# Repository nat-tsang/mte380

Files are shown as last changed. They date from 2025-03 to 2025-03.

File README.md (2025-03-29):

# Welcome to MTE380: PiDdy
We're a team of 5 students from the University of Waterloo tasked with creating a search and rescue robot to complete a course, via line following with computer vision, pick up a lego man and drop off the lego man in a safe zone. 

The course consists of a 6x6 grid of 30cm x 30cm squares, with a red tape path guiding the robot from the starting point to the target. A green tape box outlines two safe zones which the Lego man can be dropped off in. 

On game day, our robot was able to achieve times of 15 seconds on the first two runs, and 13 seconds in the third run. In total it weighed 131 g, mostly thanks to the mechanical and electrical design of the robot. The robot's software architecutre consisted of a Teensy MCU running the main control logic, and a Pixy camera module for the perception. 
# Software

This repo contains all of the software behind our robot, PiDdy. It specifically contains the PD controller for line following, the main state machine for feature arbitration between line following, picking up the lego man and dropping off the lego man.

## Code Standards

We are following OOP coding practices for clean, reusable code.

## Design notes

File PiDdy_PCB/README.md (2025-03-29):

Space for all things to do custom pcb (PiDdy's chassis)

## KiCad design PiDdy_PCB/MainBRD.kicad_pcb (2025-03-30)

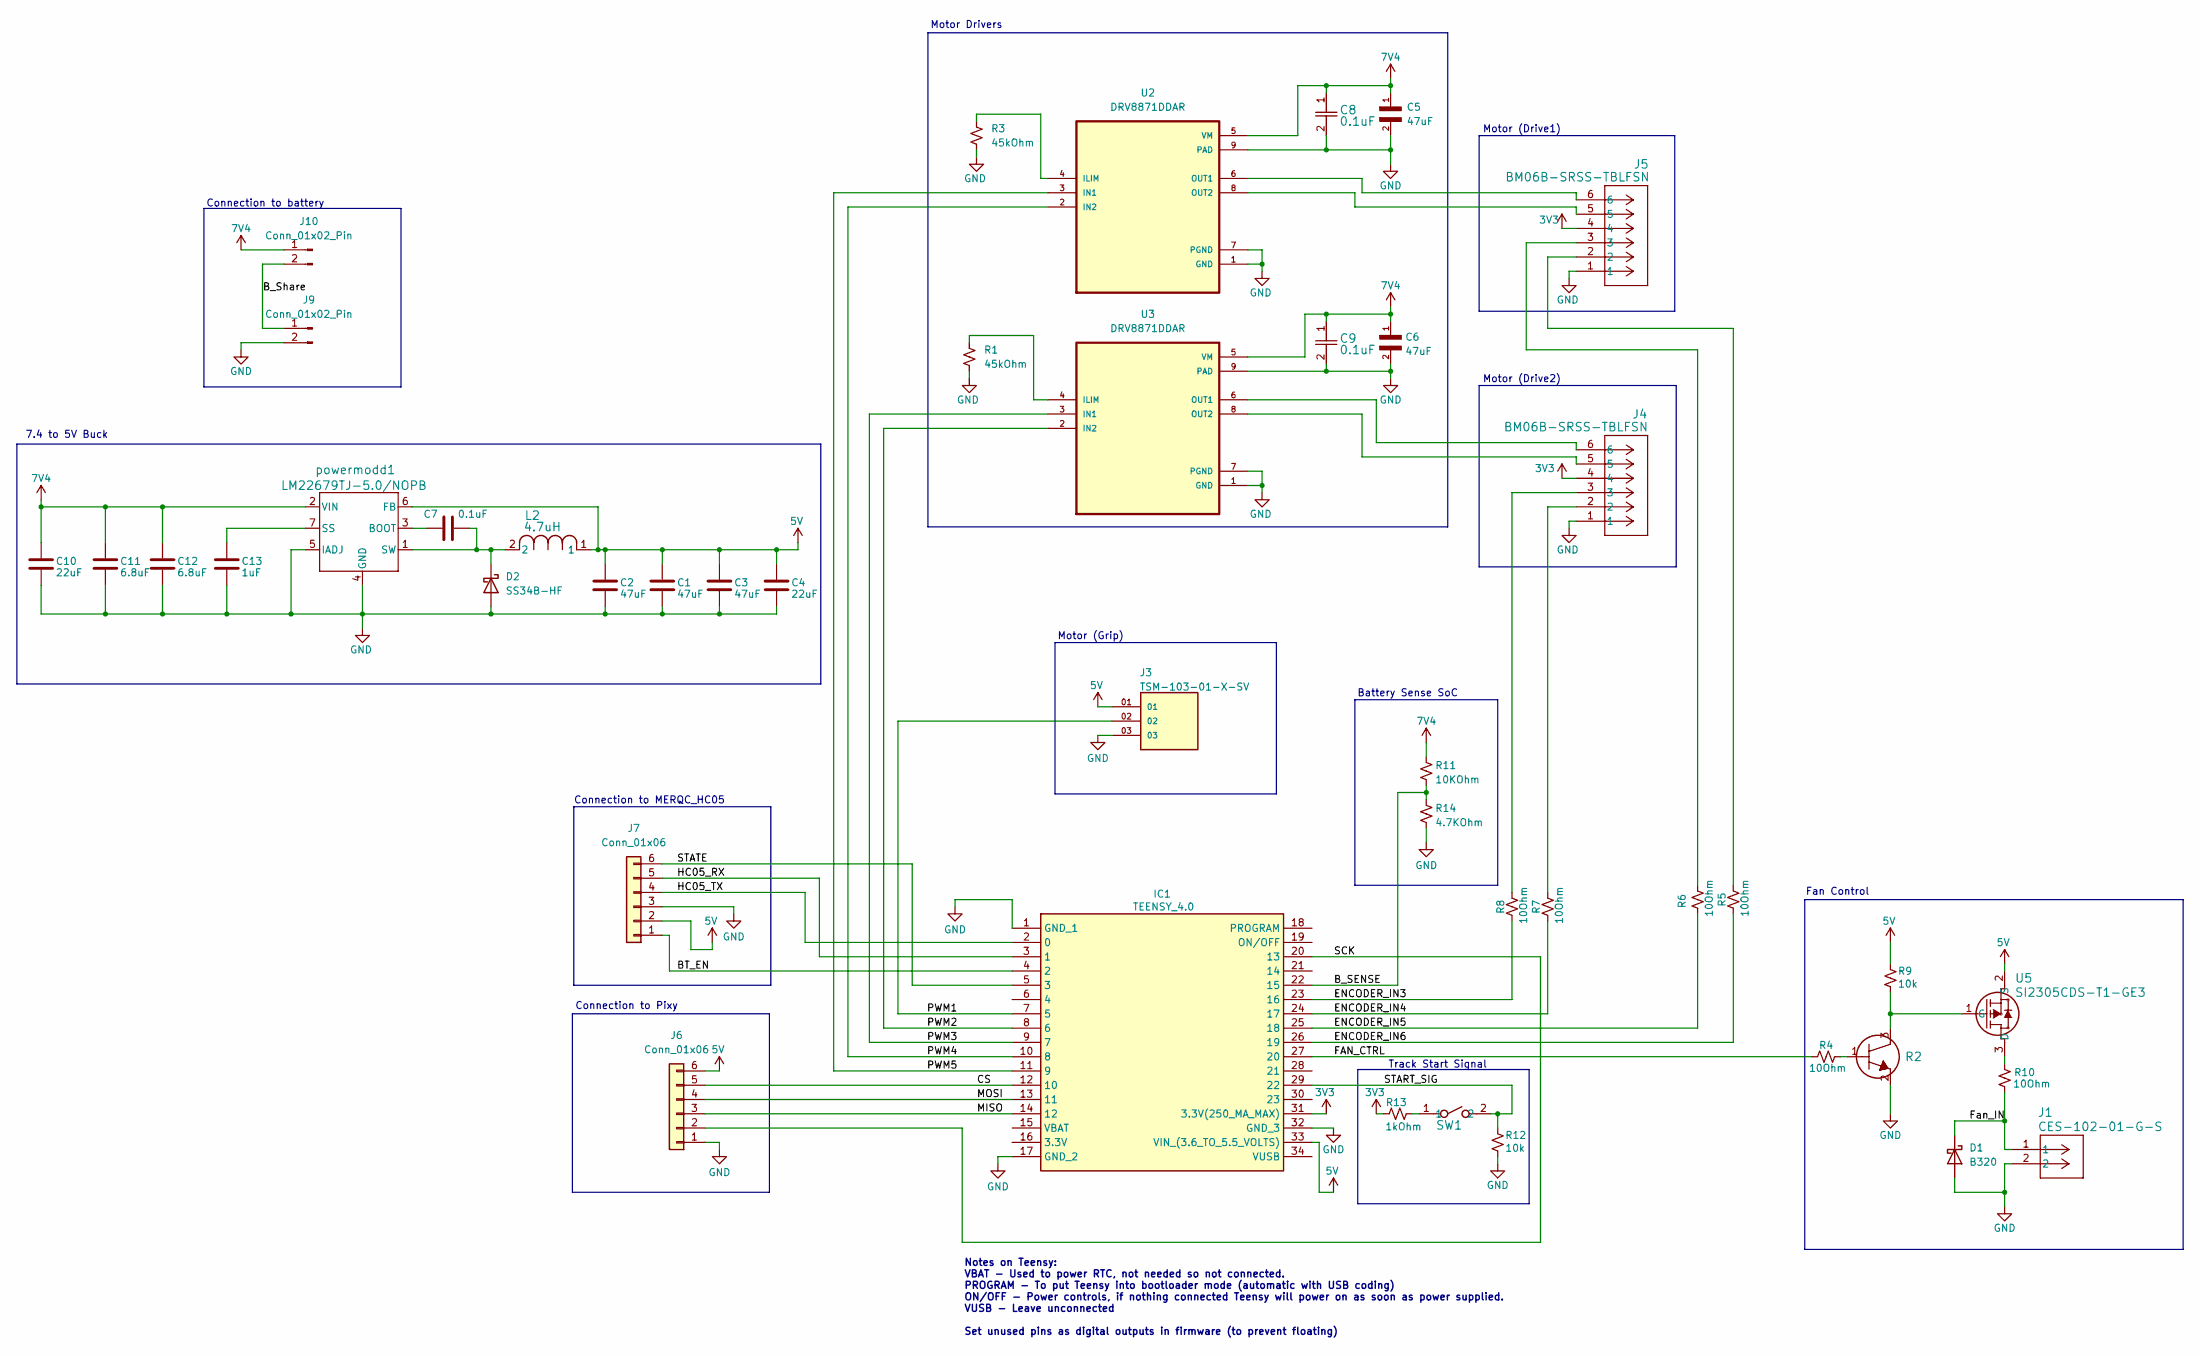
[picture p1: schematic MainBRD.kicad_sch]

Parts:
C1, C2, C3, C5, C6: 47uF; C_1210_3225Metric_Pad1.33x2.70mm_HandSolder
C4, C10: 22uF; C_1206_3216Metric_Pad1.33x1.80mm_HandSolder
C7: 0.1uF; C_0402_1005Metric_Pad0.74x0.62mm_HandSolder
C8, C9: 0.1uF; C_0402_1005Metric
C11: 6.8uF; LED_0805_2012Metric_Pad1.15x1.40mm_HandSolder
C12: 6.8uF; C_0805_2012Metric_Pad1.18x1.45mm_HandSolder
C13: 1uF; C_0402_1005Metric_Pad0.74x0.62mm_HandSolder
D1: B320; D_SMC
D2: SS34B-HF; SS34B
IC1: TEENSY_4.0; TEENSY40; Manufacturer_Part_Number TEENSY 4.0
J1: CES-102-01-G-S; CON2_1X2_TU_SLW_SAI
J3: TSM-103-01-X-SV; SAMTEC_TSM-103-01-X-SV; PARTREV D
J4, J5: BM06B-SRSS-TBLFSN; CONN_BM06B-SRSS-TB_JST
J6, J7: Conn_01x06; PinHeader_1x06_P2.54mm_Vertical
J9, J10: Conn_01x02_Pin; PinHeader_1x02_P2.54mm_Vertical
L2: 4.7uH; IND_VLS5045EX-4R7M
R1, R3: 45kOhm; RES_ERJ3EKF4532V
R2: 2SC5663T2L; TRANS_2SC5658T2_ROM
R4, R5, R6, R7, R8, R10: 10Ohm; ERJ_2RKF10R0X
R9, R12: 10k; RES_ERJ2RKF4702X
R11: 10KOhm; R_1206_3216Metric
R13: 1kOhm; ERJ_2RKF10R0X
R14: 4.7KOhm; R_1206_3216Metric
SW1: PTS636 SM50J SMTR LFS; SW_PTS636_CNK
U2, U3: DRV8871DDAR; lili_foot
U5: SI2305CDS-T1-GE3; TO-236_VIS
powermodd1: LM22679TJ-5.0/NOPB; LM22679TJ

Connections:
3V3: IC1.31 (3.3V(250_MA_MAX)), J4.4, J5.4, R13.2
5V: C1.1, C2.1, C3.1, C4.1, IC1.33 (VIN_(3.6_TO_5.5_VOLTS)), J3.01, J6.6, J7.2, L2.1, R9.1, U5.2 (S), powermodd1.6 (FB)
7V4: C5.1, C6.1, C8.1, C9.1, C10.1, C11.1, C12.1, J10.1, R11.1, U2.5 (VM), U3.5 (VM), powermodd1.2 (VIN)
/BT_EN: IC1.4 (2), J7.1
/B_SENSE: IC1.22 (15), R11.2, R14.1
/B_Share: J9.1, J10.2
/CS: IC1.12 (10), J6.5
/ENCODER_IN3: IC1.23 (16), R8.2
/ENCODER_IN4: IC1.24 (17), R7.2
/ENCODER_IN5: IC1.25 (18), R6.2
/ENCODER_IN6: IC1.26 (19), R5.2
/FAN_CTRL: IC1.27 (20), R4.2
/Fan_IN: D1.1 (K), J1.1, R10.2
/HC05_RX: IC1.3 (1), J7.5
/HC05_TX: IC1.2 (0), J7.4
/MISO: IC1.14 (12), J6.3
/MOSI: IC1.13 (11), J6.4
/PWM1: IC1.7 (5), J3.02
/PWM2: IC1.8 (6), U3.2 (IN2)
/PWM3: IC1.9 (7), U3.3 (IN1)
/PWM4: IC1.10 (8), U2.2 (IN2)
/PWM5: IC1.11 (9), U2.3 (IN1)
/SCK: IC1.20 (13), J6.2
/START_SIG: IC1.29 (22), R12.1, SW1.2
/STATE: IC1.5 (3), J7.6
GND: C1.2, C2.2, C3.2, C4.2, C5.2, C6.2, C8.2, C9.2, C10.2, C11.2, C12.2, C13.2, D1.2 (A), D2.2 (A), IC1.1 (GND_1), IC1.17 (GND_2), IC1.32 (GND_3), J1.2, J3.03, J4.1, J5.1, J6.1, J7.3, J9.2, R1.1, R2.2 (EMITTER), R3.1, R12.2, R14.2, U2.1 (GND), U2.7 (PGND), U2.9 (PAD), U3.1 (GND), U3.7 (PGND), U3.9 (PAD), powermodd1.4 (GND), powermodd1.5 (IADJ)
unnamed: C7.2, D2.1 (K), L2.2, powermodd1.1 (SW)
unnamed: J4.2, R7.1
unnamed: J4.3, R8.1
unnamed: J5.2, R5.1
unnamed: J5.3, R6.1
unnamed: R2.1 (Base), R4.1
unnamed: R2.3 (Collector), R9.2, U5.1 (G)
unnamed: R13.1, SW1.1
unnamed: R3.2, U2.4 (ILIM)
unnamed: J5.6, U2.6 (OUT1)
unnamed: J5.5, U2.8 (OUT2)
unnamed: R1.2, U3.4 (ILIM)
unnamed: J4.6, U3.6 (OUT1)
unnamed: J4.5, U3.8 (OUT2)
unnamed: R10.1, U5.3 (D)
unnamed: C7.1, powermodd1.3 (BOOT)
unnamed: C13.1, powermodd1.7 (SS)

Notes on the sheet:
Motor (Grip)
Motor (Drive1)
Connection to Pixy
Motor (Drive2)
Track Start Signal
Motor Drivers
Connection to battery
Notes on Teensy: VBAT - Used to power RTC, not needed so not connected. PROGRAM - To put Teensy into bootloader mode (automatic with USB coding) ON/OFF - Power controls, if nothing connected Teensy will power on as soon as power supplied. VUSB - Leave unconnected Set unused pins as digital outputs 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
Battery Sense SoC
Connection to MERQC_HC05
Fan Control
7.4 to 5V Buck

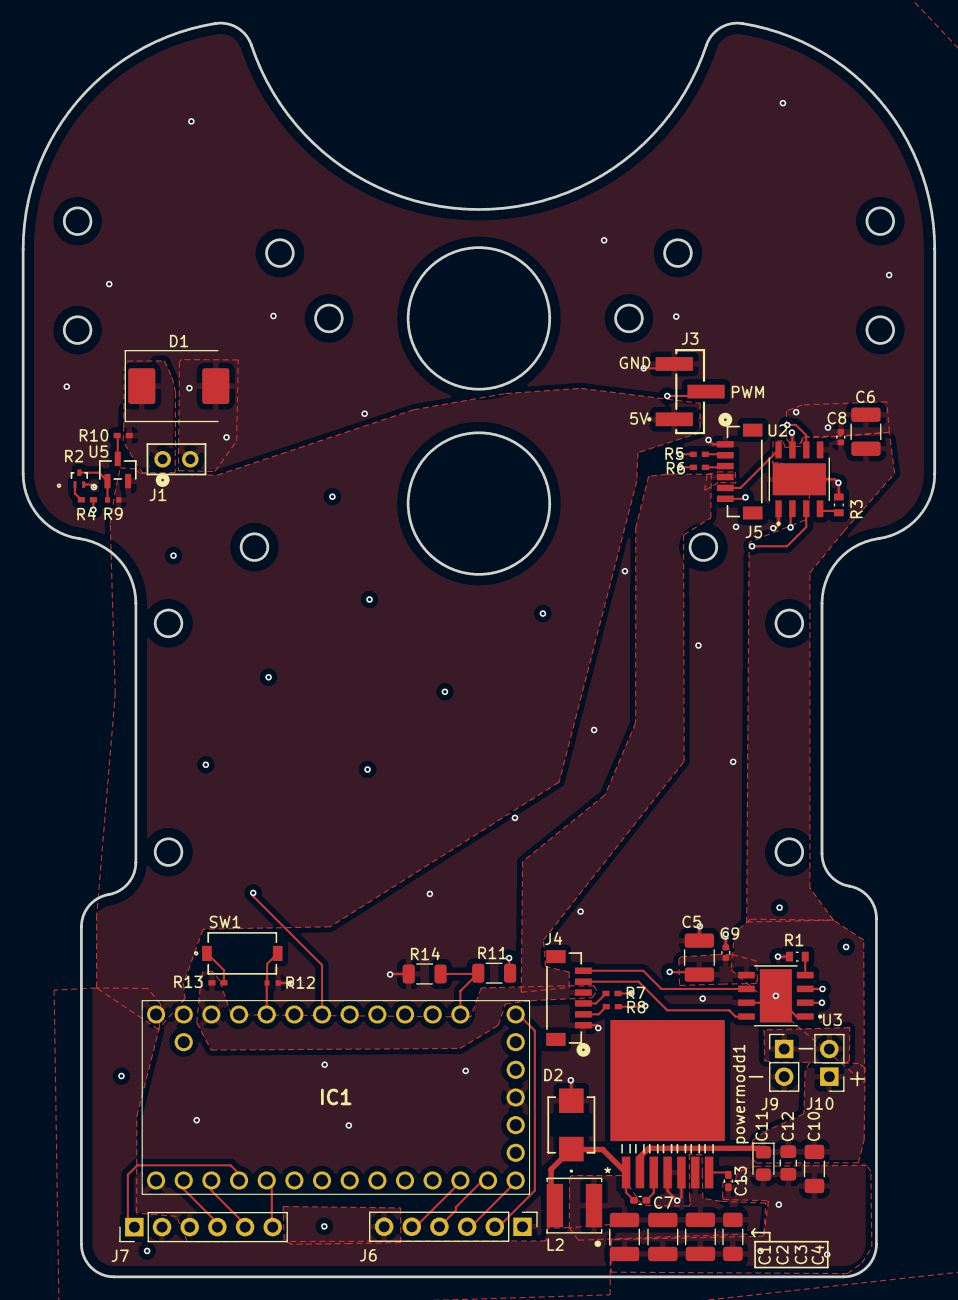
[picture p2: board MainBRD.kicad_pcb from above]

Board: 4 copper layers, 83.7 x 115.1 mm, 44 parts (0 on the bottom side), 43 nets.

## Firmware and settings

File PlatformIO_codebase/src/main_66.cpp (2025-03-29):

/**
 * @brief This main loop runs the main state diagram for Piddy with steering detection
 * THIS IS SWITCH CASE VERSION 
*/

#include <Arduino.h>
#include <Config.h>
#include <Motor.h>
#include <Fan.h>
#include <ServoGripper.h>
#include <PixyLineTracker.h>
#include <PIDController.h>
#include <Helpers.h>
#include <Filter.h>
#include <TurnController.h>
#include <EncoderReader.h>
// #define BTSerial Serial1

EncoderReader rightEncoder(ENCODER_IN6, ENCODER_IN5);
EncoderReader leftEncoder(ENCODER_IN3, ENCODER_IN4);

Motor rightMotor(u2_IN1, u2_IN2, true);
Motor leftMotor(u3_IN1, u3_IN2, false);

Fan fan(FAN);
ServoGripper gripper(SERVO, minPulse, maxPulse);

// Instantiate PID with gains from Config
PIDController linePID(LINE_KP, LINE_KI, LINE_KD);

PixyLineTracker lineTracker; // Pixy object for line, bullseye and legoman detection
Pixy2 pixy;

Filter<float, 3> pixyErrorFilter;    // For Pixy X-position (float)

bool hasTurned = false;

TurnController turnController(leftMotor, rightMotor, leftEncoder, rightEncoder, WHEEL_BASE, WHEEL_DIAMETER);

enum PiddyState {
  LINE_FOLLOW_PICKUP,
  LINE_FOLLOW_DROPOFF,
  BULLSEYE_DETECT,
  LEGOMAN_ALIGN,
  PICKUP_LEGOMAN,
  UNLOAD_SHAYLA,
  GO_HOME,
  IDLE
};

PiddyState currentState = IDLE;

// === Function Prototype ===
void printVoltageLevel(int analogPin);
void debugPrint(String msg);
bool legoManAlign(int thresholdX, int thresholdY, const Block* block, int numBlock);
float checkBatteries(int pin);
void flashPixyLight(int times);


void setup() {
  Serial.begin(115200);
  BTSerial.begin(9600);

  gripper.attach(); // Attach servo at startup
  gripper.close();

  initButton(START_SIG);  // Initialize button pin
  linePID.reset();
  //fan.turnOn(); // Turn fan on at startup

  lineTracker.begin();  // Initialize Pixy
  lineTracker.setLampOFF();

  pinMode(BATTERY_LEVEL_PIN, INPUT); // Battery level

  debugPrint("Code uploaded. STARTING ROUTINE");
  checkBatteries(BATTERY_LEVEL_PIN);  // Check battery voltage
  delay(1000);
}


void loop() {
  if (SYSTEM_SHUTDOWN) return;  // Halt program here if shutdown triggered
  // === Read battery voltage ===
  checkBatteries(BATTERY_LEVEL_PIN);  // Check battery voltage
  
  static bool lastRobotRunning = false;
  // === Check button state ===
  checkButton(leftMotor, rightMotor);  // Check button state and toggle robotRunning state

  // === State toggle logic ===
  if (robotRunning != lastRobotRunning) { // If button state changes
    if (robotRunning) {
      debugPrint("Switching to LINE_FOLLOWING");
      gripper.open();  // Optional: ready for pickup
      lineTracker.setBullseye(false);
      currentState = LINE_FOLLOW_PICKUP;
      //currentState = LINE_FOLLOW_DROPOFF;   // FOR TESTING ONLY
    } else {
      debugPrint("Switching to IDLE");
      hasTurned = false;
      leftbasePWM = 95;
      rightbasePWM = 95;
      currentState = IDLE;
    }
  }
  lastRobotRunning = robotRunning;

  pixy.ccc.getBlocks();
  const auto* blocks = pixy.ccc.blocks;
  int numBlocks = pixy.ccc.numBlocks;

  switch (currentState) {
    case IDLE:
      leftMotor.stop();
      rightMotor.stop();
      break; 

    case LINE_FOLLOW_PICKUP: {
      float pixyError = lineTracker.readLinePosition(blocks, numBlocks);  // +157.5 (far left drift) to -157.5 (far right drift)

      // TODO: Check in Pixy if the following parameters are correct
      lineTracker.findBullseye(100, 5, 30, 20, blocks, numBlocks, leftMotor, rightMotor); // currently on nightime, 175, 50, 30, 20 (daytime) 175, 50, 50, 20 (more forgiving x)
      if (lineTracker.getBullseye()) {
        leftMotor.stop();
        rightMotor.stop();
        leftMotor.setSpeed(-70); // Reverse robot
        rightMotor.setSpeed(-70);
        delay(100);
        leftMotor.stop();
        rightMotor.stop();
        flashPixyLight(1);
        leftbasePWM = 66;
        rightbasePWM = 66;
        currentState = LEGOMAN_ALIGN;
        break;
      }
      if (!lineTracker.getLineDetected()) {
        debugPrint("No line seen in LINE_FOLLOW_PICKUP");
        leftMotor.stop();
        rightMotor.stop();
        linePID.reset();
        break; 
      }

      if (abs(pixyError) < 10.0) {
        pixyError = 0;
      }
      double steeringCorrection = linePID.compute(pixyError);  // Output is differential m/s, -ve means turn left, +ve means turn right
      int leftPWM = constrain(leftbasePWM + steeringCorrection, 0, 150);
      int rightPWM = constrain(rightbasePWM - steeringCorrection, 0, 150);
      // === Apply Motor Commands ===
      leftMotor.setSpeed(leftPWM);
      rightMotor.setSpeed(rightPWM);  
      break;
    }

    case LEGOMAN_ALIGN: {
      if (legoManAlign(20, 150, blocks, numBlocks)) {
        debugPrint("Legoman centered. Switching to PICKUP_LEGOMAN");
        currentState = PICKUP_LEGOMAN;
      }
      break;
    }

    case PICKUP_LEGOMAN: {
      delay(150);
      gripper.close();
      debugPrint("Turning 180 with legoman. ");
      delay(300); // debouncing, allows gripper to fully close 
      if (!hasTurned) {
        turnController.turnDegrees(-150, 70); // 70 from testing in driveAndTurn.cpp
        hasTurned = true;
        delay(250); // Allow robot to stop and not drit past red line?
      }
      lineTracker.readLinePosition(blocks, numBlocks);
      debugPrint(lineTracker.getLineDetected());
      delay(200);
      if (lineTracker.getLineDetected()){
        lineTracker.setBullseye(false);
        linePID.reset();
        debugPrint("Switching to LINE_FOLLOW_DROPOFF");
        currentState = LINE_FOLLOW_DROPOFF;
      } else {
        turnController.turnDegrees(-30, 70);
      }
      break;
    }

    case LINE_FOLLOW_DROPOFF: {
      float pixyError = lineTracker.readLinePosition(blocks, numBlocks);  // +157.5 (far left drift) to -157.5 (far right drift)
      lineTracker.findGreenBox(0, 0, 0, 0, blocks, numBlocks); // passing in zeros because they are unused
      
      if (lineTracker.getGreenBox()) {    // TODO: Write function for turning and open servo and reverse and follow line home
        leftMotor.stop();
        rightMotor.stop();
        debugPrint("Green box found in stopping range. Setting to UNLOAD_SHAYLA");
        delay(400);
        currentState = UNLOAD_SHAYLA;

        break;
      }
      
      if (!lineTracker.getLineDetected()) {
        debugPrint("No line seen in LINE_FOLLOW_DROPOFF");
        leftMotor.stop();
        rightMotor.stop();
        linePID.reset();
        break; 
      }
      
      if (abs(pixyError) < 10.0) {
        pixyError = 0;
      }

      double steeringCorrection = linePID.compute(pixyError);  // Output is differential m/s, -ve means turn left, +ve means turn right
      int leftPWM = constrain(leftbasePWM + steeringCorrection, 0, 150);
      int rightPWM = constrain(rightbasePWM - steeringCorrection, 0, 150);
      // === Apply Motor Commands ===
      leftMotor.setSpeed(leftPWM);
      rightMotor.setSpeed(rightPWM);  
      break;
    }

    case UNLOAD_SHAYLA: {
      debugPrint("Dropping off Shayla in green box");
      turnController.turnDegrees(60, 70); // Turn to face green box
      delay(100); // Wait for turn to complete
      leftMotor.setSpeed(70); // Move robot forward
      rightMotor.setSpeed(70);
      delay(300); // Wait for robot to move forward
      leftMotor.stop();
      rightMotor.stop();
      delay(200); // Wait for robot to stop
      gripper.open();
      delay(200); // Wait for gripper to open
      leftMotor.setSpeed(-65); // Reverse robot
      rightMotor.setSpeed(-65);
      delay(500); // Wait for robot to reverse
      leftMotor.stop();
      rightMotor.stop();
      turnController.turnDegrees(65, -70); // Turn back to face line
      lineTracker.setGreenBox(false);
      debugPrint("Setting to GO_HOME");
      currentState = GO_HOME;
      break;
    }

    case GO_HOME: {
      float pixyError = lineTracker.readLinePosition(blocks, numBlocks);  // +157.5 (far left drift) to -157.5 (far right drift)

      if (!lineTracker.getLineDetected()) {
        debugPrint("No line seen in GO_HOME. Stopping");
        leftMotor.stop();
        rightMotor.stop();
        linePID.reset();
        break; 
      }

      if (abs(pixyError) < 10.0) {
        pixyError = 0;
      }

      double steeringCorrection = linePID.compute(pixyError);  // Output is differential m/s, -ve means turn left, +ve means turn right
      int leftPWM = constrain(leftbasePWM + steeringCorrection, 0, 150);
      int rightPWM = constrain(rightbasePWM - steeringCorrection, 0, 150);
      // === Apply Motor Commands ===
      leftMotor.setSpeed(leftPWM);
      rightMotor.setSpeed(rightPWM);  
      break;
    }

    default:
      // safety catch 
      leftMotor.stop();
      rightMotor.stop();
      currentState = IDLE;
      break;
  } 
}


// === Reads actual voltage using analog pin and divider ===
float checkBatteries(int pin) {
  static unsigned long lastPrintTime = 0;
  unsigned long currentTime = millis();

  float batteryVoltage = ((analogRead(pin)/ANALOG_RESOLUTION) * 3.3)/0.3197;

  // Only print every 5000 ms (5 seconds)
  if (currentTime - lastPrintTime >= 5000) {
    debugPrint("Battery Voltage: " + String(batteryVoltage));
    lastPrintTime = currentTime;
  }

  if (batteryVoltage < BATTERY_VOLTAGE_THRESHOLD) {
    debugPrint("Battery low. SYSTEM SHUTDOWN");
    SYSTEM_SHUTDOWN = true;
    currentState = IDLE;
    leftMotor.stop();
    rightMotor.stop();
    fan.turnOff();
    flashPixyLight(5);
  }
  return batteryVoltage;
}

// === Flashes Pixy cam lamp ===
void flashPixyLight(int times) {
  for (int i = 0; i < times; i++) {
    pixy.setLamp(1, 1); // LEDs ON
    delay(100);
    pixy.setLamp(0, 0); // LEDs OFF
    delay(100);
  }
}

bool legoManAlign(int thresholdX, int thresholdY, const Block* block, int numBlock) {     // TODO: Do we need to call get blocks again?
  auto [x, y] = lineTracker.getPixyCoord(6, block, numBlock); // orange shayla is 6,  TODO: Put in config
  debugPrint("Shayla x: " + String(x) + "   |   y: " + String(y));

  if (x >= 0 && y >= 0) {
    int x_error = (X_CENTER + 4) - x; // positive if legoman is to the left, negative if legoman is to the right
    debugPrint("Shayla x_error: " + String(x_error));

    if (abs(x_error) < thresholdX && y > thresholdY) { 
      debugPrint("Shayla is centered, stopping");
      leftMotor.stop();
      rightMotor.stop();
      return true;
    } 
    else {
      if (abs(x_error) < thresholdX) { 
        debugPrint("Shayla is centered");
        // drive forward only once Shayla is centered
        if (y < thresholdY) { // Legoman is too far, drive forward slowly
          debugPrint("Legoman is too far");
          leftMotor.setSpeed(75);
          rightMotor.setSpeed(75);
          debugPrint("Left PWM: " + String(leftMotor.getSpeed()) + "  |   Right PWM: " + String(rightMotor.getSpeed()));
          delay(100);
          leftMotor.setSpeed(0);
          rightMotor.setSpeed(0);
          delay(75);
        }
      }
      else if (abs(x_error) > thresholdX) {    // Turn robot on it's center axis
        debugPrint("Shayla is not centered");
        //int turnSpeed = abs(x_error * LEGO_KPx);    // Positive means turn right, negative means turn left
        if (x_error > 0) {   // Positive means turns left  
          leftMotor.setSpeed(0);
          rightMotor.setSpeed(75);
          delay(100);
          debugPrint("Left PWM: " + String(leftMotor.getSpeed()) + "  |   Right PWM: " + String(rightMotor.getSpeed()));
          leftMotor.setSpeed(0);
          rightMotor.setSpeed(0);
          delay(75); 
        }
        else if (x_error < 0) {  // Negative means turns right
          leftMotor.setSpeed(75);
          rightMotor.setSpeed(0);
          debugPrint("Left PWM: " + String(leftMotor.getSpeed()) + "  |   Right PWM: " + String(rightMotor.getSpeed()));
          delay(100);
          leftMotor.setSpeed(0);
          rightMotor.setSpeed(0);
          delay(75);
        }
      }
    }
  } else {   // Lego man not detected, TODO: spin till in view 
    debugPrint("Shayla is not found, pulsing forward");
    leftMotor.setSpeed(75);
    rightMotor.setSpeed(75);
    debugPrint("Left PWM: " + String(leftMotor.getSpeed()) + "  |   Right PWM: " + String(rightMotor.getSpeed()));
    delay(100);
    leftMotor.setSpeed(0);
    rightMotor.setSpeed(0);
    delay(75);
  }
  return false;
}

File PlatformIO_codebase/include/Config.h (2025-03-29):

#pragma once // “Include this file only once when compiling, even if it’s included multiple times elsewhere.”
#include <Arduino.h>

// Motor pins
const int u2_IN2 = 8;  // Right motor
const int u2_IN1 = 9;  
const int u3_IN2 = 6;  // Left motor
const int u3_IN1 = 7;  

// Encoder Pins
// Moving fwd will increase encoder count
const int ENCODER_IN3 = 16; // Drive 2 connected to U3
const int ENCODER_IN4 = 17; // Drive 2
const int ENCODER_IN5 = 18; // Drive 1 NEW PINS (right) connected to U2
const int ENCODER_IN6 = 19; // Drive 1 NEW PINS

const int START_SIG = 22; // Pin 22 is connected to button

const int SERVO = 5;
const int minPulse = 700;   // open
const int maxPulse = 2000;  // closed

const int FAN = 20;

const int BATTERY_LEVEL_PIN = 15;
const float ANALOG_RESOLUTION = 1023.0; // 10-bit resolution (0–1023)
const float BATTERY_VOLTAGE_THRESHOLD = 7.4;  // Shutdown voltage threshold

// Calibration settings
const int CALIBRATION_PWM = 65;  // Tune based on your motor response
const int CALIBRATION_TIME = 10000; // ms

// PID Gains for Line Following
const float LINE_KP = 0.63;     // Proportional gain
const float LINE_KI = 0.0;     // Integral gain (start with 0, add if necessary)
const float LINE_KD = 0.14;     // Derivative gain

// PID Gains for Velocity Control
const float LEFT_VELOCITY_KP = 5; // Proportional gain
const float LEFT_VELOCITY_KI = 0.3; // Integral gain (start with 0, add if necessary)
const float LEFT_VELOCITY_KD = 0; // Derivative gain

const float RIGHT_VELOCITY_KP = 5; // Proportional gain
const float RIGHT_VELOCITY_KI = 0.3; // Integral gain (start with 0, add if necessary)
const float RIGHT_VELOCITY_KD = 0; // Derivative gain

const float RIGHT_KF = 45;  
const float LEFT_KF = 50;

// Robot Constants
const float WHEEL_BASE = 0.08; // Distance between wheels in meters
const float WHEEL_DIAMETER = 0.021; // Wheel diameter in meters
const float COUNTS_PER_WHEEL_REV = 120.0;  // Real-world counts per wheel rev
const float WHEEL_CIRCUMFERENCE = PI * WHEEL_DIAMETER; // meters
const float LEGO_KPx = 0.1 ; // Proportional gain for x-axis
const float LEGO_KPy = 0.3;

// Pixy CCC params
const float X_CENTER = 315.0/2.0;
const float Y_CENTER = 207.0/2.0;
const int LEGO_SIG = 4;
const int GREEN_BOX_SIG = 3;
const int BULLSEYE_SIG = 2;
const int REDLINE_SIG = 1;

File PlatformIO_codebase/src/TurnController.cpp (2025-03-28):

#include "TurnController.h"
#include "PixyLineTracker.h"
#include "Config.h"
#include "Helpers.h"

TurnController::TurnController(Motor& leftM, Motor& rightM, EncoderReader& leftE, EncoderReader& rightE, float wheelBaseMeters, float wheelDiameterMeters)
    : leftMotor(leftM), rightMotor(rightM), leftEncoder(leftE), rightEncoder(rightE), wheelBase(wheelBaseMeters) {
    wheelCircumference = PI * WHEEL_DIAMETER;
}

void TurnController::turnDegrees(float degrees, int turnSpeed) {
    // Reset encoders
    leftEncoder.reset();
    rightEncoder.reset();

    // Calculate the arc length each wheel needs to travel
    float turnCircumference = PI * WHEEL_BASE;
    float arcLength = (abs(degrees) / 360.0) * turnCircumference;  // meters

    // Calculate equivalent encoder ticks for this arc length
    float metersPerTick = wheelCircumference / COUNTS_PER_WHEEL_REV;
    long targetTicks = arcLength / metersPerTick;

    // Determine turn direction
    int leftSpeed = degrees > 0 ? turnSpeed : -turnSpeed;
    int rightSpeed = -(leftSpeed+4);

    // Start turning
    leftMotor.setSpeed(leftSpeed);
    rightMotor.setSpeed(rightSpeed);

    // Monitor encoder ticks until target reached
    while (abs(leftEncoder.getTicks()) < targetTicks && abs(rightEncoder.getTicks()) < targetTicks) {
        // Optionally print progress
        BTSerial.print("Left ticks: "); BTSerial.print(abs(leftEncoder.getTicks()));
        BTSerial.print(" | Right ticks: "); BTSerial.print(abs(rightEncoder.getTicks()));
        BTSerial.print(" | Target ticks: "); BTSerial.println(targetTicks);
        delay(10);
    }

    // Stop motors after turn
    leftMotor.stop();
    rightMotor.stop();
}

void TurnController::turnToShayla(int turnSpeed, const Block* block, int numBlock)
{
    float turnCircumference = PI * WHEEL_BASE;
    float arcLength = (20.0 / 360.0) * turnCircumference;
    float metersPerTick = wheelCircumference / COUNTS_PER_WHEEL_REV;
    long targetTicks = arcLength / metersPerTick;

    int spinLimit = 0;
    bool foundShayla = false;

    while (!foundShayla && spinLimit < (360/20)) {
        leftEncoder.reset();
        rightEncoder.reset();

        // Determine turn direction
        int leftSpeed = turnSpeed;
        int rightSpeed = -(turnSpeed+4);

        leftMotor.setSpeed(leftSpeed);
        rightMotor.setSpeed(rightSpeed);

        while (abs(leftEncoder.getTicks()) < targetTicks && abs(rightEncoder.getTicks()) < targetTicks) {
            BTSerial.print("Left ticks: "); BTSerial.print(abs(leftEncoder.getTicks()));
            BTSerial.print(" | Right ticks: "); BTSerial.println(abs(rightEncoder.getTicks()));
            delay(10);
        }

        leftMotor.stop();
        rightMotor.stop();

        if (numBlock > 0) {
            for (int i = 0; i < numBlock; i++) {
                if (block[i].m_signature == LEGO_SIG) {
                    debugPrint("Found shayla.");
                    foundShayla = true;
                    break;
                }
            }
        }

        if (!foundShayla) {
            debugPrint("Still can't find Shayla.");
            spinLimit++;
            if (spinLimit >= (360/20)) {
                debugPrint("Spun 360 degrees and no Shayla found. Exiting.");
            }
        }

        delay(200); // Optional pause before next spin
    }
}

// void repositionToShay(int turnSpeed, int degrees, int drivr) {
//     // Reset encoders
//     leftEncoder.reset();
//     rightEncoder.reset();

//     // Calculate the arc length each wheel needs to travel
//     float turnCircumference = PI * WHEEL_BASE;
//     float arcLength = (abs(degrees) / 360.0) * turnCircumference;  // meters

//     // Calculate equivalent encoder ticks for this arc length
//     float metersPerTick = wheelCircumference / COUNTS_PER_WHEEL_REV;
//     long targetTicks = arcLength / metersPerTick;

//     // Determine turn direction
//     int leftSpeed = degrees > 0 ? turnSpeed : -turnSpeed;
//     int rightSpeed = -(leftSpeed+4);

//     // Start turning
//     leftMotor.setSpeed(leftSpeed);
//     rightMotor.setSpeed(rightSpeed);

//     // Monitor encoder ticks until target reached
//     while (abs(leftEncoder.getTicks()) < targetTicks && abs(rightEncoder.getTicks()) < targetTicks) {
//         // Optionally print progress
//         BTSerial.print("Left ticks: "); BTSerial.print(abs(leftEncoder.getTicks()));
//         BTSerial.print(" | Right ticks: "); BTSerial.print(abs(rightEncoder.getTicks()));
//         BTSerial.print(" | Target ticks: "); BTSerial.println(targetTicks);
//         delay(10);
//     }

//     // Stop motors after turn
//     leftMotor.stop();
//     rightMotor.stop();    
// }

// void TurnController::turnToLegoMan(int turnSpeed, const Block* block, int numBlock)
// {    float turnCircumference = PI * WHEEL_BASE;
//     float arcLength = (30.0 / 360.0) * turnCircumference;
//     float metersPerTick = wheelCircumference / COUNTS_PER_WHEEL_REV;
//     long targetTicks = arcLength / metersPerTick;

//     int spinLimit = 0;
//     bool foundRedLine = false;

//     while (!foundRedLine && spinLimit < 12) {
//         leftEncoder.reset();
//         rightEncoder.reset();

//         // Determine turn direction
//         int leftSpeed = turnSpeed;
//         int rightSpeed = -turnSpeed;

//         leftMotor.setSpeed(leftSpeed);
//         rightMotor.setSpeed(rightSpeed);

//         while (abs(leftEncoder.getTicks()) < targetTicks && abs(rightEncoder.getTicks()) < targetTicks) {
//             BTSerial.print("Left ticks: "); BTSerial.print(abs(leftEncoder.getTicks()));
//             BTSerial.print(" | Right ticks: "); BTSerial.println(abs(rightEncoder.getTicks()));
//             delay(10);
//         }

//         leftMotor.stop();
//         rightMotor.stop();

//         if (numBlock > 0) {
//             for (int i = 0; i < numBlock; i++) {
//                 if (block[i].m_signature == REDLINE_SIG) {
//                     debugPrint("Red line detected.");
//                     foundRedLine = true;
//                     break;
//                 }
//             }
//         }

//         if (!foundRedLine) {
//             debugPrint("No red line detected.");
//             spinLimit++;
//             if (spinLimit >= 12) {
//                 debugPrint("Spun 360 degrees and no red line found. Exiting.");
//             }
//         }

//         delay(200); // Optional pause before next spin
//     }
// }

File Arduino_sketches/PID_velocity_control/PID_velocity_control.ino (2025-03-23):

#include <Pixy2.h>
#include <Encoder.h>

// Pixy2 Object
Pixy2 pixy;

// Motor & Encoder Pins
const int ENCODER_IN3 = 16; // Left encoder
const int ENCODER_IN4 = 17;
const int ENCODER_IN5 = 14; // Right encoder
const int ENCODER_IN6 = 21;

const int u2_IN2 = 8;  // Right motor
const int u2_IN1 = 9;  
const int u3_IN2 = 6;  // Left motor
const int u3_IN1 = 7;  

const int START_SIG = 22; // Start button

// Encoder objects
Encoder drive1Encoder(ENCODER_IN5, ENCODER_IN6); // Right
Encoder drive2Encoder(ENCODER_IN3, ENCODER_IN4); // Left

// PID Constants (Tune these values)
double Kp_line = 0.5;   // Line following proportional gain
double Ki_line = 0.0;   // Integral gain (may not be needed)
double Kd_line = 0.08;  // Derivative gain

double Kp_speed = 0.016; // Speed control proportional gain

// Target speed in encoder ticks per second
float base_speed = 1600; // Adjust as needed
float motor_calibration = 1.0045; // Adjust after testing

// PID Variables
double setpoint = 157.5; // Center of Pixy2 frame (315/2)
double previous_error = 0;
double integral = 0;
unsigned long previous_time = 0;

bool go = false;

// Motor PWM values
int leftPWMOutput = 70;
int rightPWMOutput = 70;

// Previous encoder positions
long prevLeftPos = 0;
long prevRightPos = 0;
unsigned long lastTime = 0;

void setup() {
  Serial.begin(115200);
  pinMode(u2_IN1, OUTPUT);
  pinMode(u2_IN2, OUTPUT);
  pinMode(u3_IN1, OUTPUT);
  pinMode(u3_IN2, OUTPUT);
  pinMode(START_SIG, INPUT_PULLDOWN);
  
  pixy.init();
  pixy.changeProg("color_connected_components");

  drive1Encoder.write(0);
  drive2Encoder.write(0);
  
  previous_time = millis();
  delay(5000); // Delay for setup
}

void loop() {
  unsigned long current_time = millis();
  double dt = (current_time - previous_time) / 1000.0;
  previous_time = current_time;

  int buttonState = digitalRead(START_SIG);
  if (buttonState) {
      while(digitalRead(START_SIG)){
          Serial.println("Button still pressed. Take finger off.");
      }
      go = !go;
  }

  if (go) {
      // Get color features from Pixy
      pixy.ccc.getBlocks();

      if (pixy.ccc.numBlocks > 0) {
          for (int i = 0; i < pixy.ccc.numBlocks; i++) {
              if (pixy.ccc.blocks[i].m_signature == 1) {
                  int x = pixy.ccc.blocks[i].m_x;
                  double error = setpoint - x;
                  if (abs(error) < 5) { error = 0; } // Deadzone

                  // PID calculations for line following
                  integral += error * dt;
                  double derivative = (error - previous_error) / dt;
                  double output = Kp_line * error + Ki_line * integral + Kd_line * derivative;
                  previous_error = error;

                  // Adjust target speeds based on PID output
                  float left_target_speed = base_speed + output;
                  float right_target_speed = base_speed - output;

                  // Speed control loop
                  updateMotorSpeeds(left_target_speed, right_target_speed);
              } 
              else if (pixy.ccc.blocks[i].m_signature == 2) {
                  if (pixy.ccc.blocks[i].m_width > 30 && pixy.ccc.blocks[i].m_height > 64) {
                      setMotorSpeeds(0, 0);
                      go = false;
                      Serial.println("Bullseye Detected in range");
                  } else {
                      Serial.println("No bullseye in stopping range");
                  }
              }
          }
      } else {
          setMotorSpeeds(0, 0);
          Serial.println("No line detected");
      }
  } else {
      setMotorSpeeds(0, 0);
  }
}

void updateMotorSpeeds(float left_target_speed, float right_target_speed) {
    unsigned long currentTime = millis();
    float deltaTime = (currentTime - lastTime) / 1000.0;

    if (deltaTime >= 0.01) { 
        long currentLeftPos = drive2Encoder.read();
        long currentRightPos = drive1Encoder.read();

        float left_speed = (currentLeftPos - prevLeftPos) / deltaTime;
        float right_speed = (currentRightPos - prevRightPos) / deltaTime;

        float left_error = left_target_speed - left_speed;
        float right_error = right_target_speed - right_speed;

        leftPWMOutput += Kp_speed * left_error;
        rightPWMOutput += Kp_speed * right_error;

        leftPWMOutput = constrain(leftPWMOutput, 0, 240);
        rightPWMOutput = constrain(rightPWMOutput, 0, 240);

        setMotorSpeeds(leftPWMOutput, rightPWMOutput);

        Serial.print("L error: "); Serial.print(left_error);
        Serial.print(" | R error: "); Serial.print(right_error);
        Serial.print(" | Left Speed: "); Serial.print(left_speed);
        Serial.print(" | Right Speed: "); Serial.print(right_speed);
        Serial.print(" | Left PWM: "); Serial.print(leftPWMOutput);
        Serial.print(" | Right PWM: "); Serial.println(rightPWMOutput);

        prevLeftPos = currentLeftPos;
        prevRightPos = currentRightPos;
        lastTime = currentTime;
    }
}

void setMotorSpeeds(int left_speed, int right_speed) {
    if (left_speed > 0) {
        analogWrite(u3_IN1, left_speed);
        analogWrite(u3_IN2, LOW);
    } else {
        analogWrite(u3_IN1, LOW);
        analogWrite(u3_IN2, -left_speed);
    }

    if (right_speed > 0) {
        analogWrite(u2_IN1, LOW);
        analogWrite(u2_IN2, right_speed);
    } else {
        analogWrite(u2_IN1, -right_speed);
        analogWrite(u2_IN2, LOW);
    }
}

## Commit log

2025-03-17 trial and error pixy threading
    [Test_simple_thread_pixy.ino, Test_thread_pixy.ino]
2025-03-18 PID control edit
2025-03-18 Change PD to track middle of the vector
2025-03-18 PID control pins changes
2025-03-18 Fixed colour api logic
    [PID_control_color.ino]
2025-03-18 update of current pid control
2025-03-20 Update for design spec gripper test
2025-03-20 edit file name for pid control line
2025-03-20 New line pid tuning file
2025-03-21 Testing velocity control in .h file
2025-03-22 first script to test encoders
2025-03-22 Functions for controlling motors
2025-03-23 Set speed function fix
    [Config.h, Motor.cpp]
2025-03-23 add filter
2025-03-23 adding button
2025-03-24 Velocity control
2025-03-24 stashing current commits
2025-03-24 Update for PiDdy control with only steering, and adding switch statements for state control
2025-03-25 Edits to make similar to arduino
2025-03-25 Fixed button logic
2025-03-25 Revert to compute sma
    [Config.h]
2025-03-25 add ema filter to pid tuning
2025-03-25 Changed pixy error type to float
    [TurnController.cpp]
2025-03-25 lego align error fixes
    [legoManAlign.cpp]
2025-03-27 BT and voltage sensing
2025-03-28 turn from button push
2025-03-28 Added motor parameters to findBulleye func
2025-03-29 push the pwm
2025-03-30 Final Game Day PCB Files
    [MainBRD.kicad_pcb, MainBRD.kicad_sch]
